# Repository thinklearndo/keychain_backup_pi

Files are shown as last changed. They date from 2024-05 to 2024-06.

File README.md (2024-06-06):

# keychain_backup_pi

## What is Keychain Backup Pi?

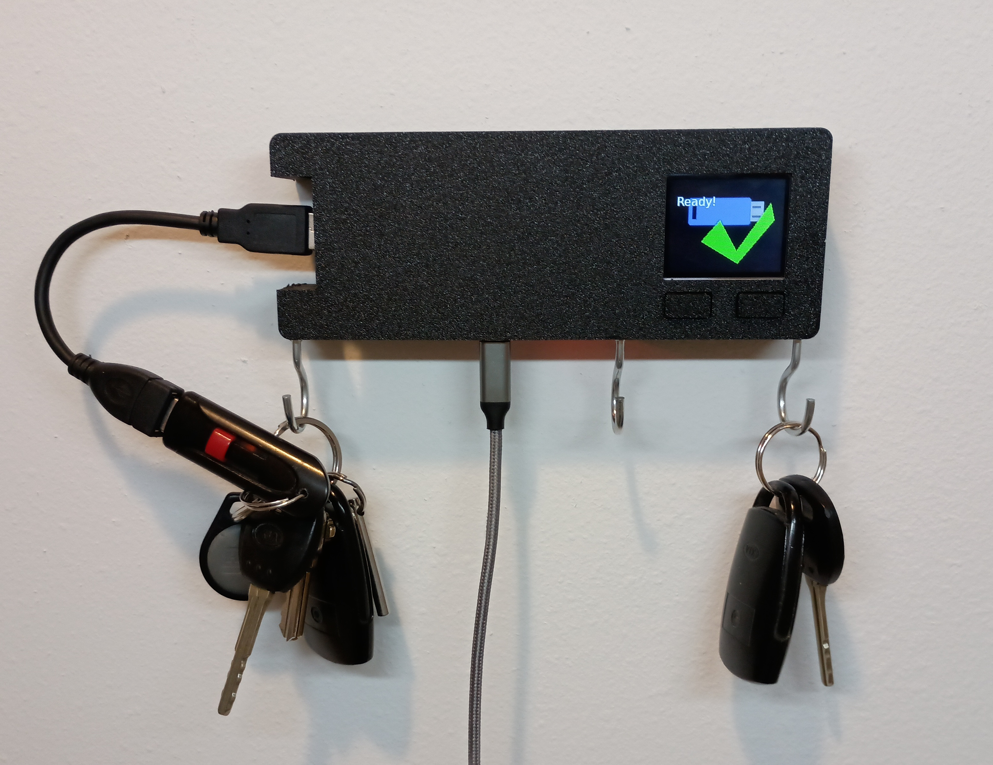
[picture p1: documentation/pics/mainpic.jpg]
 

This project is a backup system that allows keeping your important files with you all the time! Simply plug in your USB drive when you hang up your keys at night, backups run overnight over wifi, and in the morning take your freshly backed up files when you grab your keys. All powered by that amazing linux SBC, the raspberry pi.

## Improvements in this version:

* OLED LCD to give status and feedback.
* 2 buttons for interaction.
* Faster backups, 5-8 Mbytes/sec
* Easier access to the USB drive, using an extension cable.

## How it works:

Plug in you USB drive into the USB extension cable and hang your keys on a hook.

The LCD will display Ready! when the drive is ready for backups.

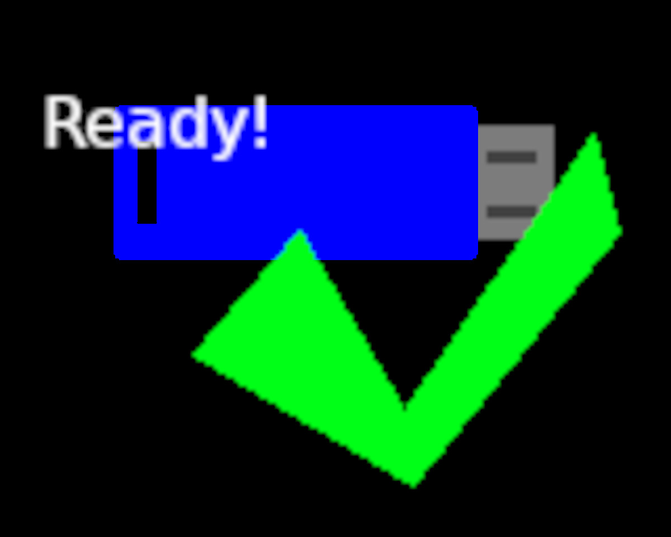
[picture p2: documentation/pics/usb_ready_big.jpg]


Let backups run over night.

In the morning when you are ready to take your keys, press one of the buttons on the front of the case. After a few moments, the LCD will show Safe to remove. Unplug the usb drive and take your keys.

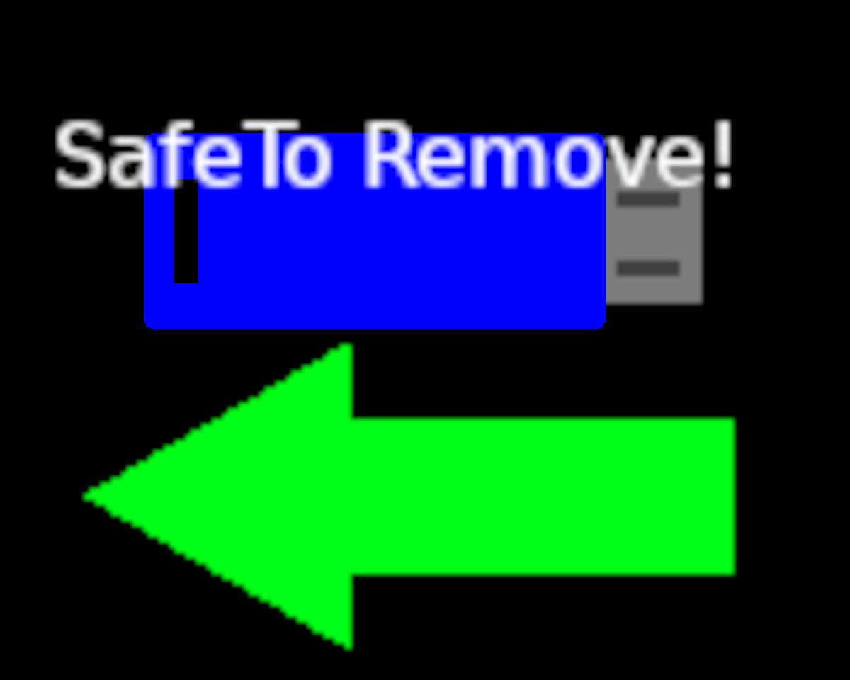
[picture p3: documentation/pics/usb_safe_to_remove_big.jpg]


## Setup

1. Follow the steps in [image flashing](documentation/imageFlashing.md) to get your sdcard setup with the keychain backup image.
2. If you aren't using the kit, [build from scratch](documentation/buildingFromScratch.md).
3. [Assemble the hardware](documentation/assembly.md).
4. [Mount it on the wall](documentation/mounting.md).

Finally, setup backups:

[Setup Duplicati for Windows, Mac and Linux](documentation/duplicatiSetup.md)

[Android file syncing instructions](documentation/androidSync.md)

[iPhone file syncing instructions](documentation/iphoneSync.md)

------------------
Please Note:

THE SOFTWARE IS PROVIDED “AS IS”, WITHOUT WARRANTY OF ANY KIND, EXPRESS OR IMPLIED, INCLUDING BUT NOT LIMITED TO THE WARRANTIES OF MERCHANTABILITY, FITNESS FOR A PARTICULAR PURPOSE AND NONINFRINGEMENT. IN NO EVENT SHALL THE AUTHORS OR COPYRIGHT HOLDERS BE LIABLE FOR ANY CLAIM, DAMAGES OR OTHER LIABILITY, WHETHER IN AN ACTION OF CONTRACT, TORT OR OTHERWISE, ARISING FROM, OUT OF OR IN CONNECTION WITH THE SOFTWARE OR THE USE OR OTHER DEALINGS IN THE SOFTWARE.

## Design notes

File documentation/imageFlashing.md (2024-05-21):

# Flashing the keychain backup image
Prerequisites:

Raspberry pi imager application installed, get it from here: https://www.raspberrypi.com/software/

SD card inserted into the computer

Image downloaded from our [release page.](https://github.com/thinklearndo/keychain_backup_pi/releases)

-----------

1. Run the pi imager application.
2. Click the Choose Device button.

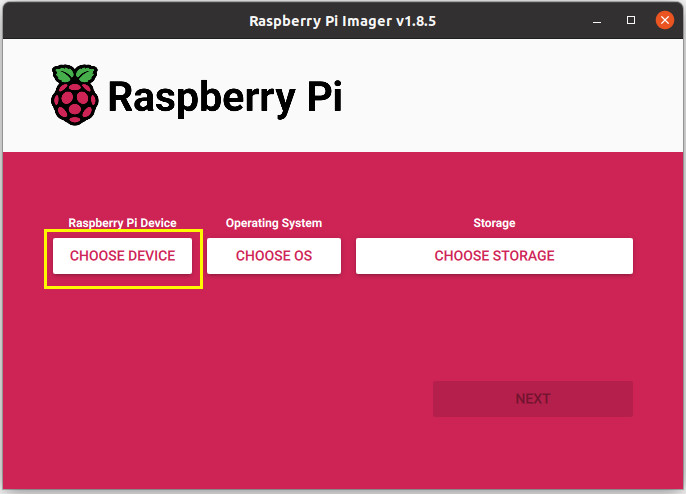
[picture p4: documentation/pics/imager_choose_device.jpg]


3. Select your raspberry pi. I have a raspberry pi 3a+ so I've selected Raspberry Pi 3.

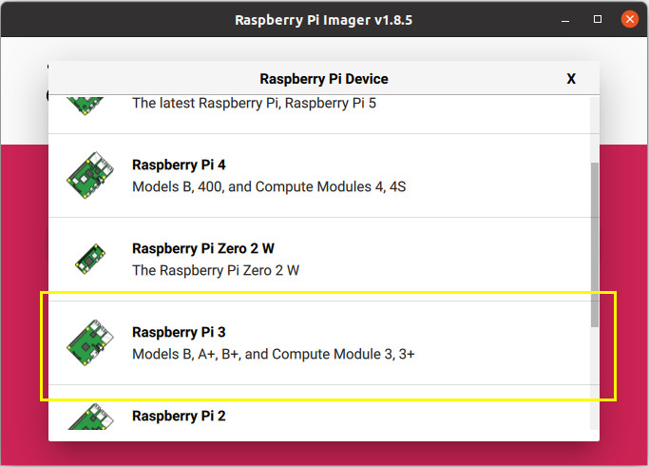
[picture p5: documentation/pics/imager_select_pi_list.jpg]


4. Back at the main screen click Choose OS.

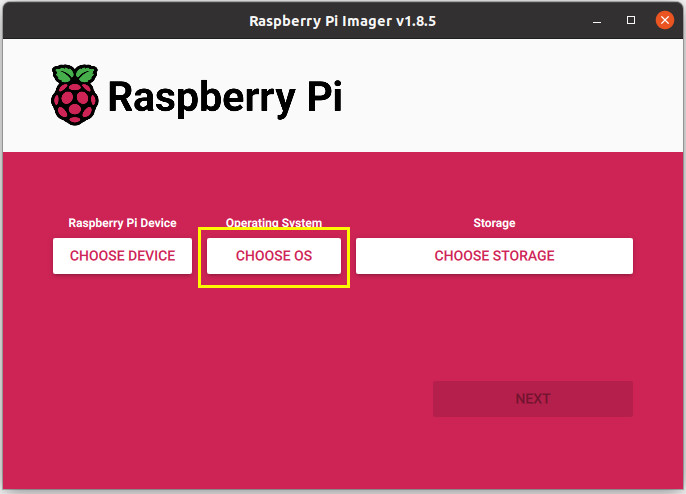
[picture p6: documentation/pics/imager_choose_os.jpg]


5. Scroll down to the bottom and select Use Custom.

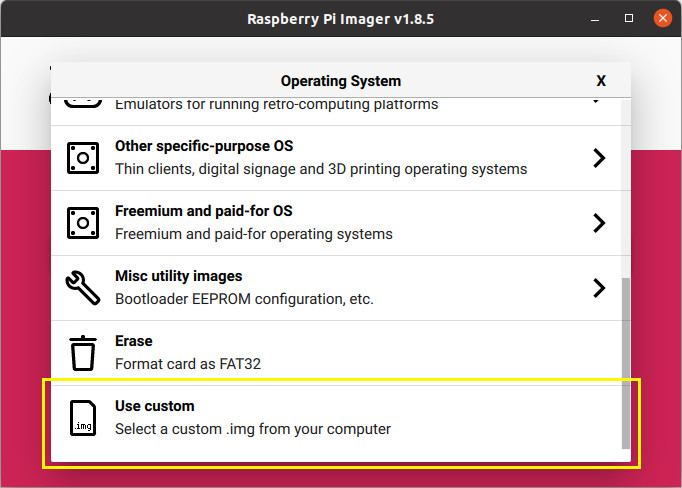
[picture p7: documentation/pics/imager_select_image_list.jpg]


6. Browse to the image file downloaded from our release page and click open.

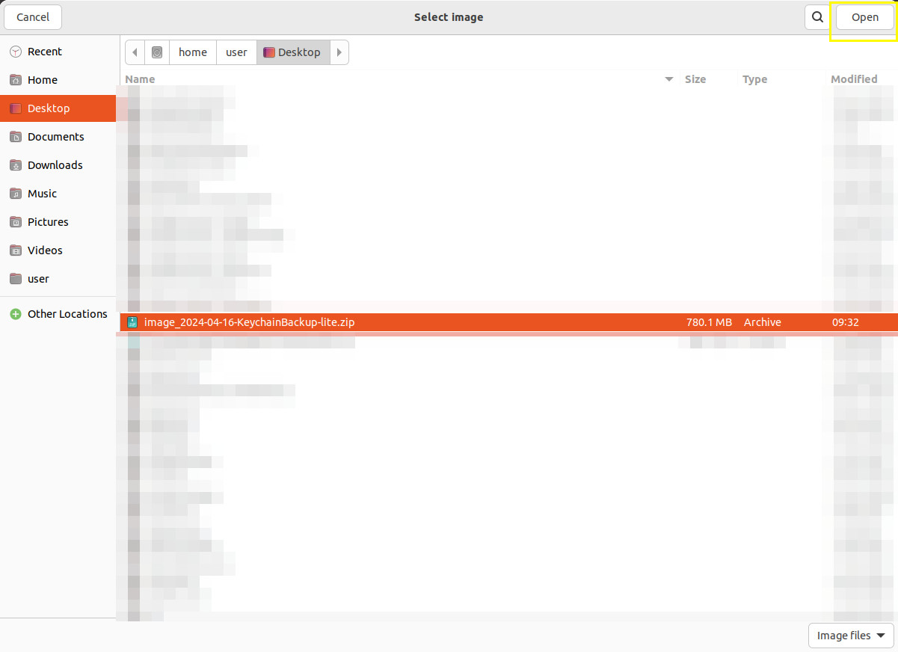
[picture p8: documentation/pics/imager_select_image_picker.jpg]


9. Click Choose storage button.

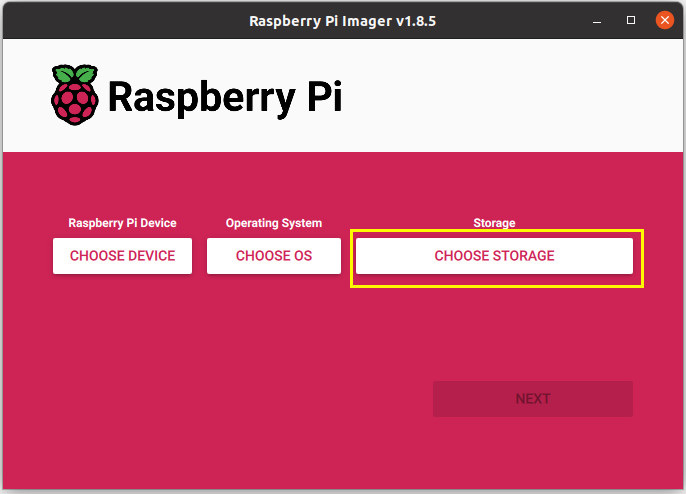
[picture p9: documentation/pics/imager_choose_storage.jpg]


10. Select the SD card you have inserted.

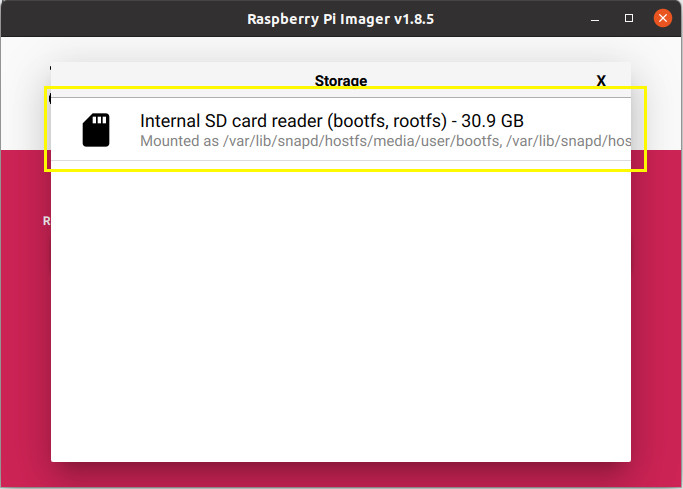
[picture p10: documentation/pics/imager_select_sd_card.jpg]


12. Click the Next button.

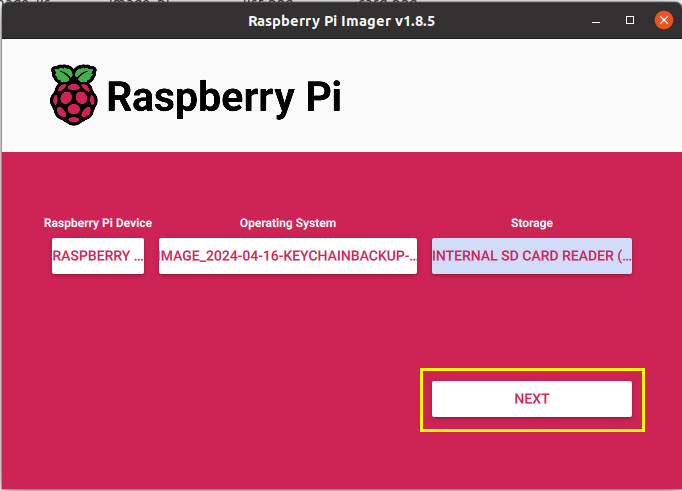
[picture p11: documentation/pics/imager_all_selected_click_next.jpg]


13. A Customise OS screen will pop up. Click edit settings.

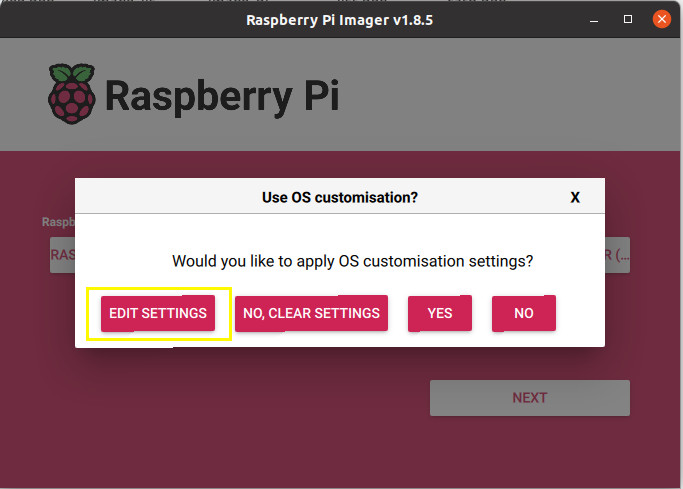
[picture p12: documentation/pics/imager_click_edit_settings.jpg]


14. On the General tab, Enter a hostname for the raspberry pi. This will make it easier to connect to later on. Also put in a username and password. You will need this later, so make a note of these values. Then set the wifi ssid and password.

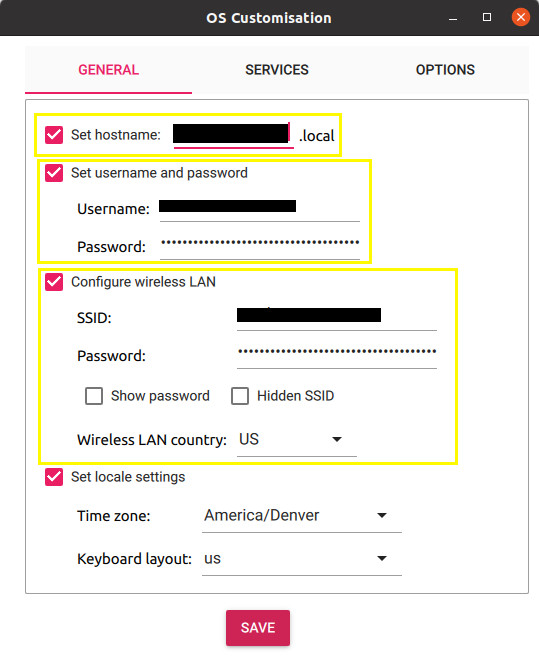
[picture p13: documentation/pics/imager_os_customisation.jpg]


15. Click on the Services tab. Make sure Enable SSH is checked and Use password authentication is selected. Then click the save button.

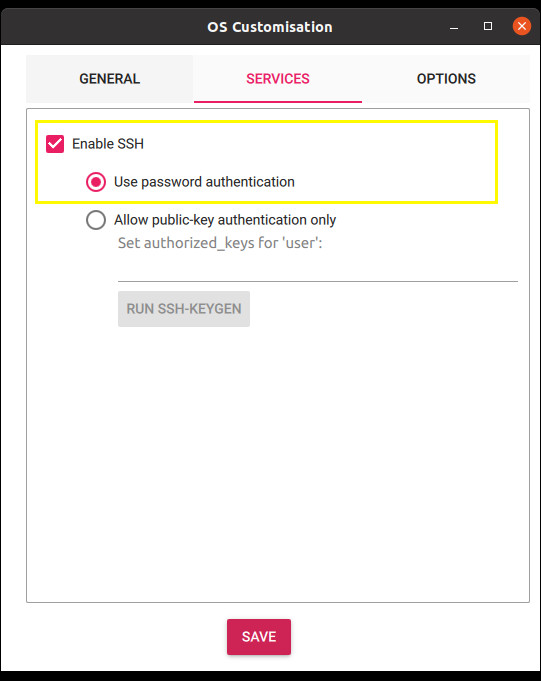
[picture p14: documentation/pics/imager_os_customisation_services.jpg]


16. Click on Yes, apply settings.

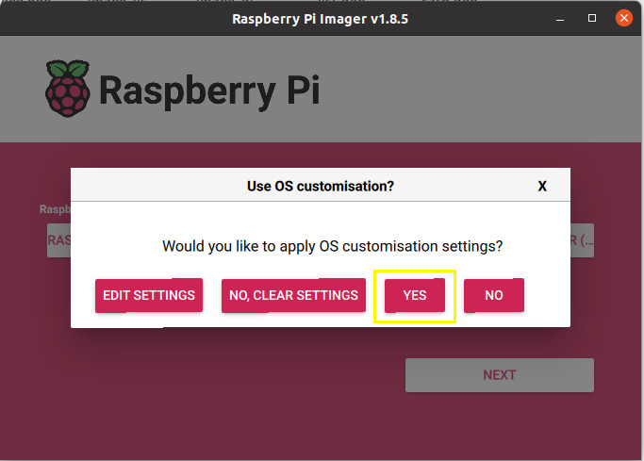
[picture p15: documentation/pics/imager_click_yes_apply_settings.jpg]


17. A warning will pop up about overwriting data, verify the right device is selected and click Yes.

18. Once the Write has finished, remove the SD card from the computer and insert it into the Raspberry PI. You are now ready to do the hardware setup, [Hardware Assembly](assembly.md).

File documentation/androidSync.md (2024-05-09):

## Using FolderSync app to sync files from Android to keychain backup

Before running this setup doc, make sure the USB drive is inserted into your Keychain backup device.

Install FolderSync app from the Play Store.

-----

1. Click create folderpair button.

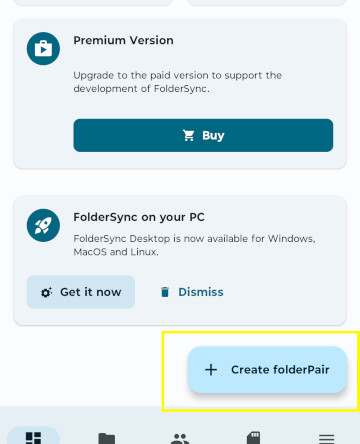
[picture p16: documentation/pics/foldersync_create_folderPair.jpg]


2. Give the folderpair a name and click next.

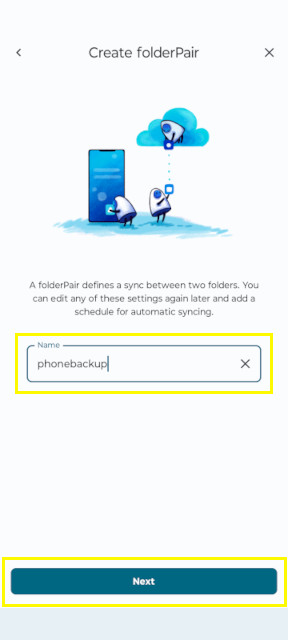
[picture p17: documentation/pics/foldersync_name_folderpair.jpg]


3. Leave Sync engine v2 selected and click next.

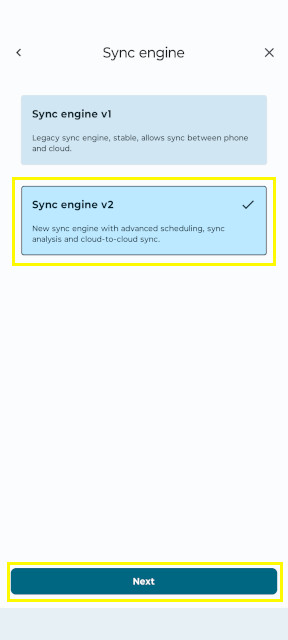
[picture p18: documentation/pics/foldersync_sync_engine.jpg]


4. Select To right folder and click next.

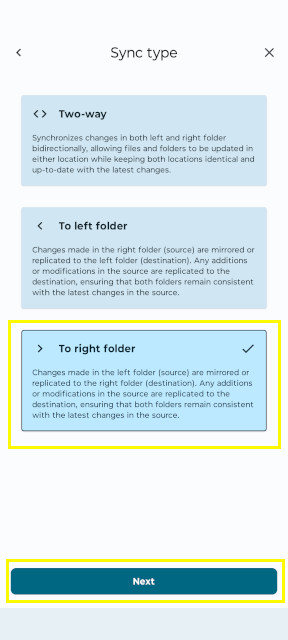
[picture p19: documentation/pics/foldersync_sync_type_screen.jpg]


5. On the Sync folders click on Select folder under Left folder.

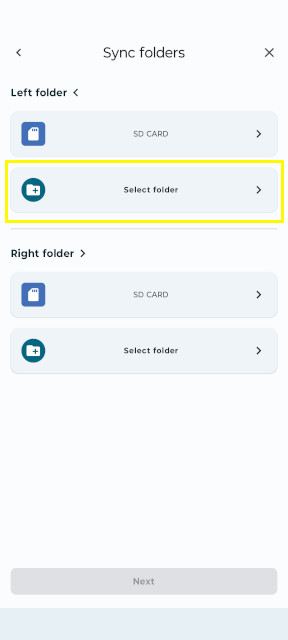
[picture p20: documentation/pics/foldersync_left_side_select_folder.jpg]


6. Select the folder to be backed up. For pictures and videos on Android, that would be the DCIM folder. Then click Select.

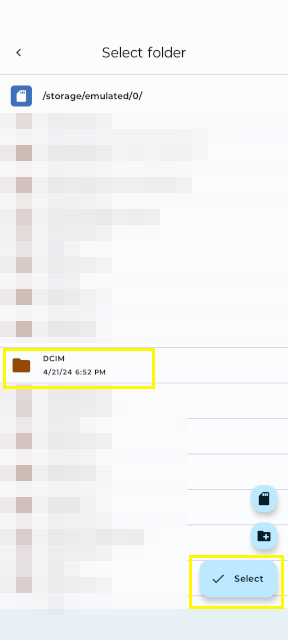
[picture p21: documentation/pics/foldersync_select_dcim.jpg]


7. Back at the Sync folders screen, under Right folder click on SD CARD.

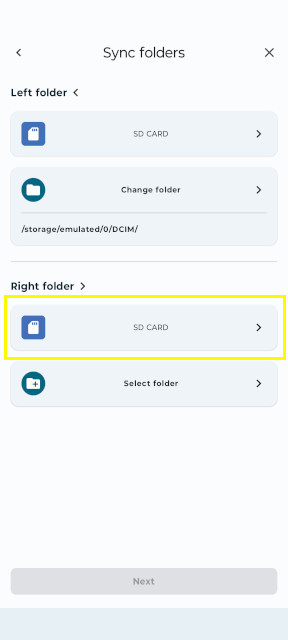
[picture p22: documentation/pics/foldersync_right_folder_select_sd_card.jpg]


8. Click Add account.

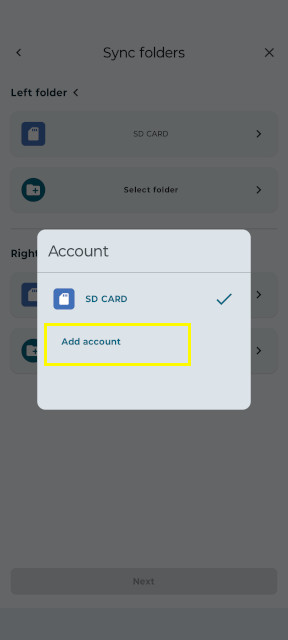
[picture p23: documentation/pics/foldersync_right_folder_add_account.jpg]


9. Scroll to the bottom and select SFTP under File protocols.

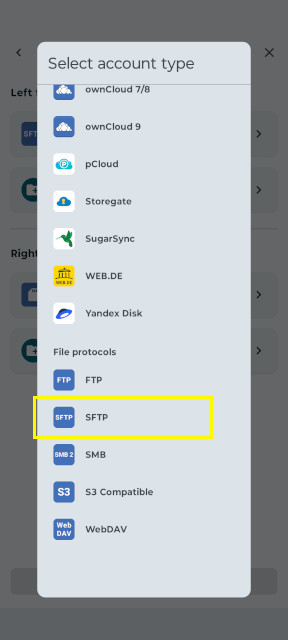
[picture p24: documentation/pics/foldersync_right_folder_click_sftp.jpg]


10. Click on the little pencil in the upper right corner and give the account a name.

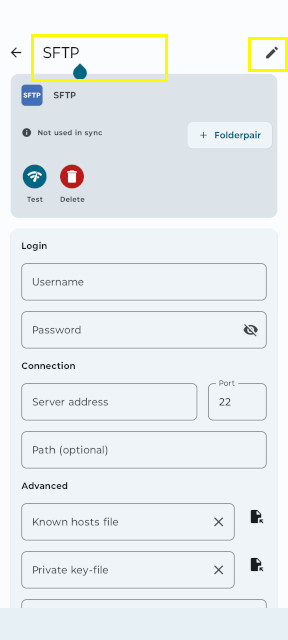
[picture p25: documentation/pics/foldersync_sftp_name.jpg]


11. Under login, enter the username and password you used to setup the raspberry pi.

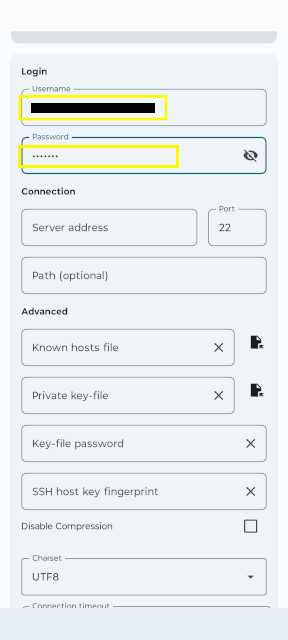
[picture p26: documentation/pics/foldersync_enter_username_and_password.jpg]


12. Under Connection, in the server address box, put in the IP address or host name of the keychain backup device and in the Port box put 2222.

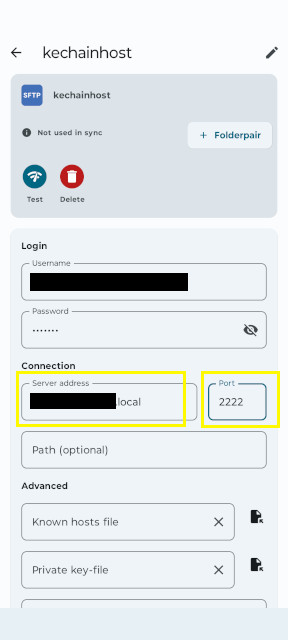
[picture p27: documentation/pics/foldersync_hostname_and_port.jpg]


13. Once all the info has been entered, click the back arrow in the upper left corner.



14. Back at the Sync folders screen, click on the SD CARD button under Right folder again. Select the newly created host.



15. In the Select folder window, click media, then click usbdrive.



16. Then click the Add folder button in the lower right corner.



17. In the create folder screen, enter a descriptive name for this backup storage location. This will allow mulitple android devices to backup to this USB drive.



18. Then click on the newly created folder.



19. Finally click on Select button.



20. Then click Next on the Sync folders screen.



21. Then click save.



22. To run the sync operation, click Sync.



23. To schedule syncs, click the Scheduling button.



24. Then click + schedule.

25. After setting up the schedule click save.

26. To verify that files are syncing, after the sync finishes, safely remove the usb drive and plug it into a computer. Open a file browser window and go to the usb device folder. Verify that the expected files are there.

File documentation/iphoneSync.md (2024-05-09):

### Setting up syncing for iPhone
----

Steps:

1. Install PhotoBackup from the app store (https://apps.apple.com/us/app/photobackup-backup-photos-and-videos-via-rsync/id945026388)

2. Allow PhotoBackup to connect to devices on your local network.



3. Click on Computer and enter in the hostname or IP address of your keychain backup device.



4. Enter your SSH credentials for your raspberry pi.



5. For remote folder enter /media/usbdrive



6. Allow PhotoBackup to access your photos.



7. Click Backup Camera Roll to backup your photos and videos to keychain backup.



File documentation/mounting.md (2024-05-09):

### Mounting the keyholder on the wall

-------------------

Tools needed:

* Pencil
* Drill
* 3/8" drill bit
* Screwdriver

Steps:

1. Place the wall bracket on the wall and mark screw holes with a pencil.



2. Remove the wall bracket and drill out the holes with a 3/8" drill bit.

3. Insert dry wall screw holders into the holes.



4. Align wall bracket with screw holes and screw 2 wall mounting screws, to secure it to the wall.



5. Align holes on top of the case with the holes on top of the wall bracket.



6. Screw in 2 - M4x5mm screws through the top of the case into the top of the wall bracket.



7. Connect strain relief USB extension cord to the side port.



8. Plug in the power to the raspberry pi by plugging in the USB cord to the micro USB port on the bottom of the pi's board. It will take up to a minute for the pi to turn on and the screen to show status messages.





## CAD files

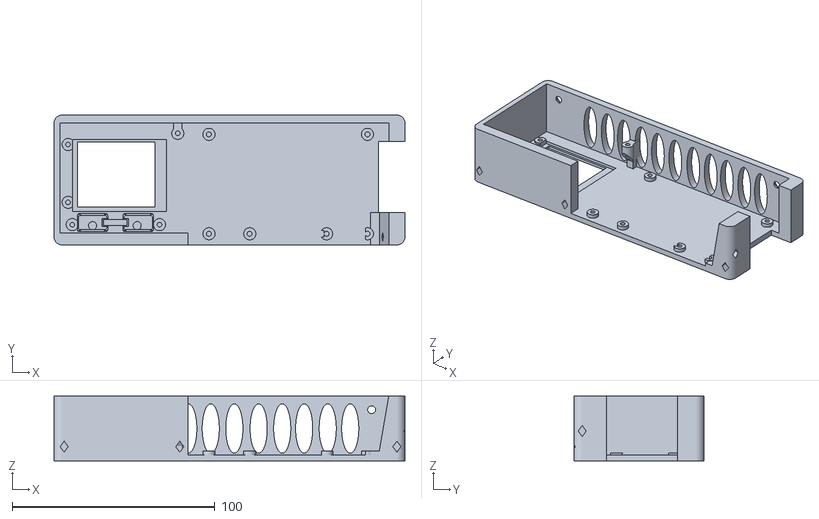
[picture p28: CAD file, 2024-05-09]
hardwarefiles/stl/keychain case.stl
173.0 x 64.0 x 32.0

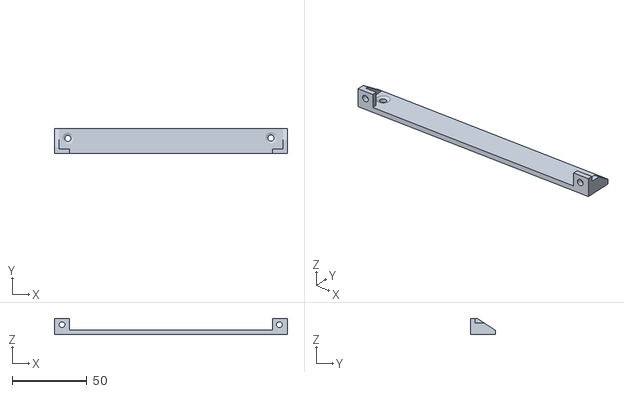
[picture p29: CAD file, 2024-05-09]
hardwarefiles/stl/wall mount.stl
156.0 x 17.0 x 11.0

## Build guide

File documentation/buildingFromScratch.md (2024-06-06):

# Building from Scratch

Get one of the connector PCB's made:

Raspberry pi 3a+ gerbers [hardwarefiles/pcb/pi3a](https://github.com/thinklearndo/keychain_backup_pi/tree/main/hardwarefiles/pcb/pi3a)

Raspberry pi 3b+ gerbers [hardwarefiles/pcb/pi3b](https://github.com/thinklearndo/keychain_backup_pi/tree/main/hardwarefiles/pcb/pi3b)

### Parts needed to finish the PCB:

2x 6x6x8mm SMD normally open SPST Momentary tactile switches (something like DTSM-65N-V-B, [mouser link](https://www.mouser.com/ProductDetail/Diptronics/DTSM-65N-V-B?qs=gTYE2QTfZfSXwXAGPNekUg%3D%3D))

1x 1x8 2.54mm pitch female header

1x 2x12 2.54mm pitch female header

### Other parts needed:

1x 1.8" oled lcd spi (here's one on [amazon](https://www.amazon.com/Display-Module-ST7735-128x160-STM32/dp/B07BFV69DZ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))

3x 1.25" Screw-in Cup Hooks

2x #6 screws and drywall mounts

2x m4x5mm screws

8x m2.6x4mm screws

Solder headers and buttons onto board:

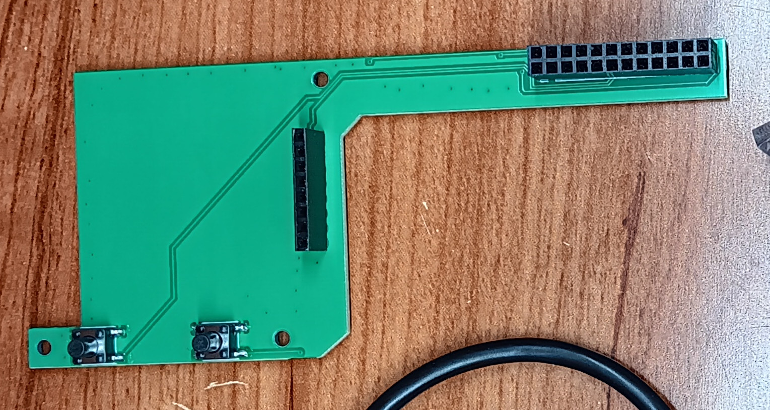
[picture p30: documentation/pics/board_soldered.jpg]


### Make the case:

Print out the [case](https://github.com/thinklearndo/keychain_backup_pi/blob/main/hardwarefiles/stl/keychain%20case.stl)

Print out the [wall bracket](https://github.com/thinklearndo/keychain_backup_pi/blob/main/hardwarefiles/stl/wall%20mount.stl)

Now you're ready to do the [hardware assembly](https://github.com/thinklearndo/keychain_backup_pi/blob/main/documentation/assembly.md)

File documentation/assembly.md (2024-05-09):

# Hardware Assembly

1. Plug in OLED LCD into 8 pin connection on the PCB.

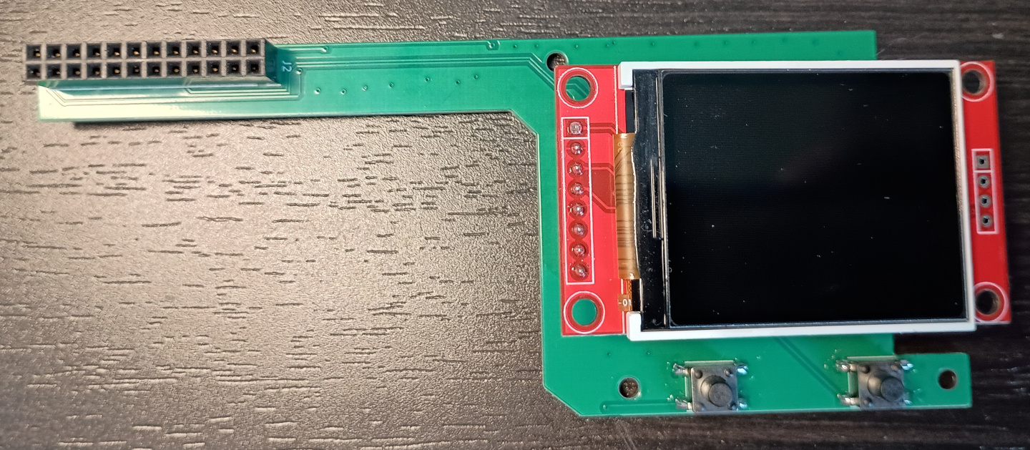
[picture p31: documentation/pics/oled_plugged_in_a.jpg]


2. Attach PCB to Raspberry pi expansion port.
   
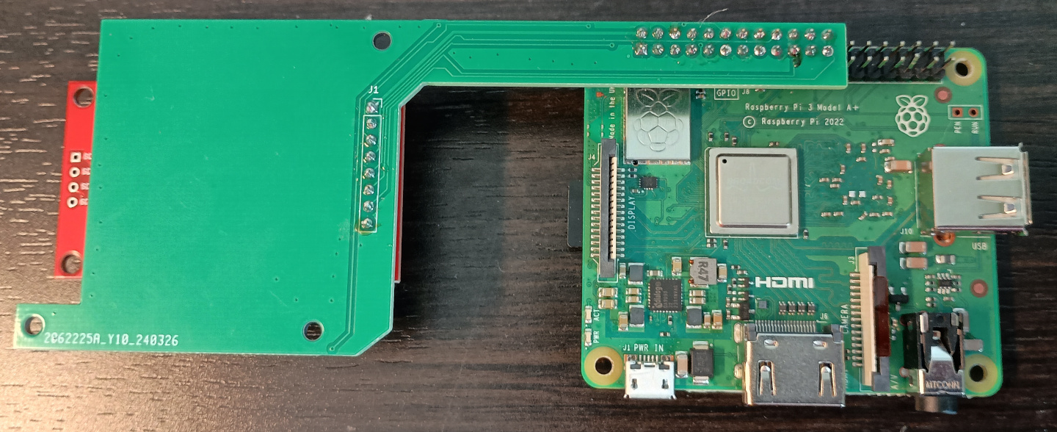
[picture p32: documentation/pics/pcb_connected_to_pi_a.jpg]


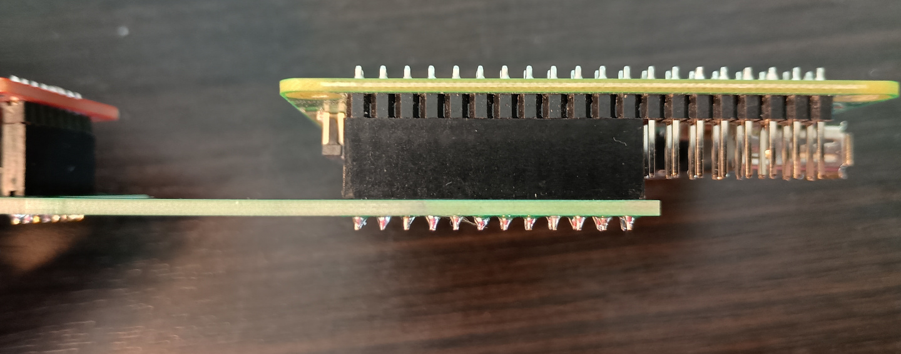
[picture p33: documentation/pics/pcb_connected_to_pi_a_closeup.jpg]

   
3. Screw in OLED LCD, PCB and Raspberry pi into the case. Be aware the buttons need to stick out of the case while screwing in the pcb.

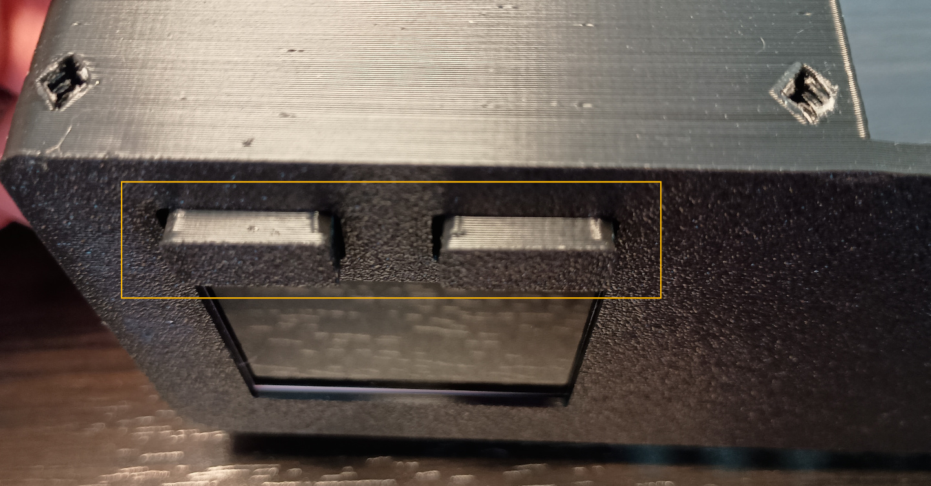
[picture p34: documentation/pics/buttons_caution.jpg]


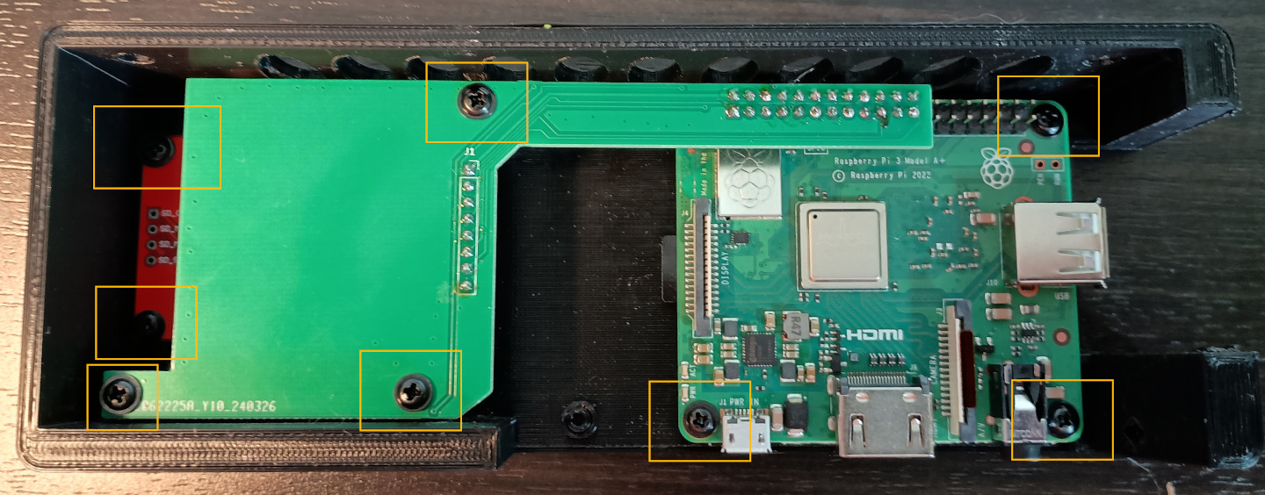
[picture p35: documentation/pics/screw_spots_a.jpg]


4. Screw in hooks to bottom of case.

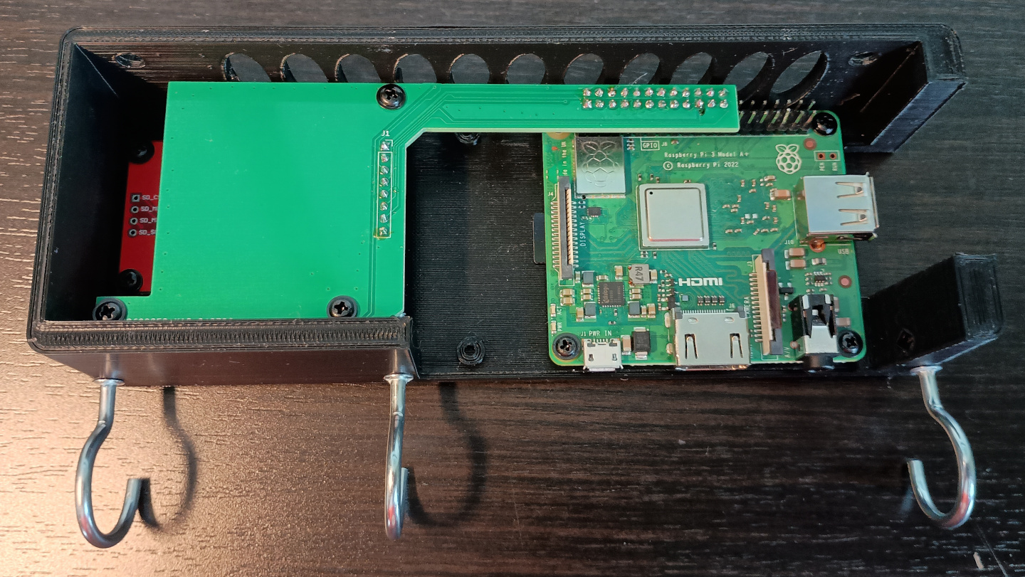
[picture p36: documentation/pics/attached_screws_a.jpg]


Now onto mounting the case on the wall: [Mounting the case](mounting.md)

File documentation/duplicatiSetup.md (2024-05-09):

## Using Duplicati to backup files to keychain backup

Before running this setup doc, make sure the USB drive is inserted into your Keychain backup device.

Download and install Duplicati for your platform: [https://duplicati.com/download](https://duplicati.com/download)

-----

1. Click add backup.

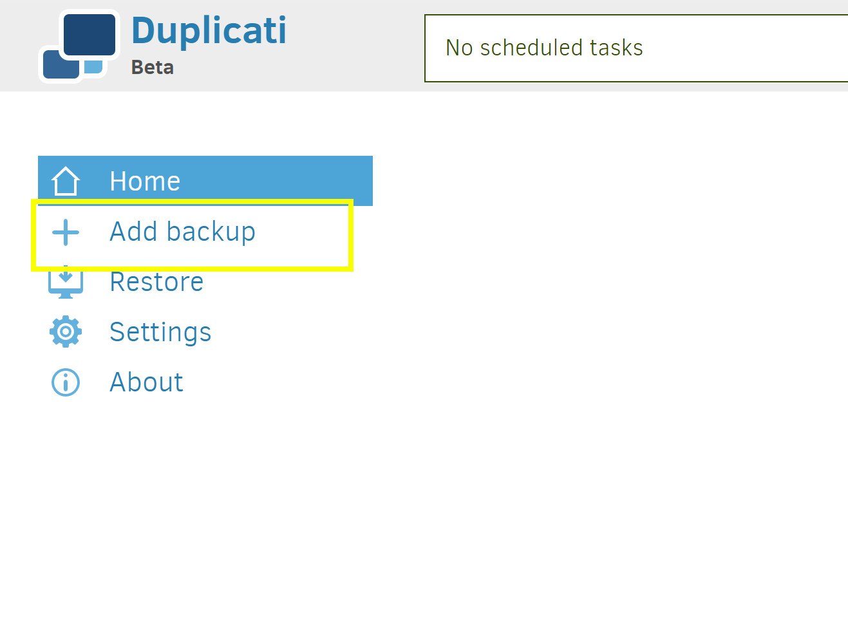
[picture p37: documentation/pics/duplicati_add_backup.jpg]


2. On Add a new backup screen, make sure Configure a new backup is selected and click Next.

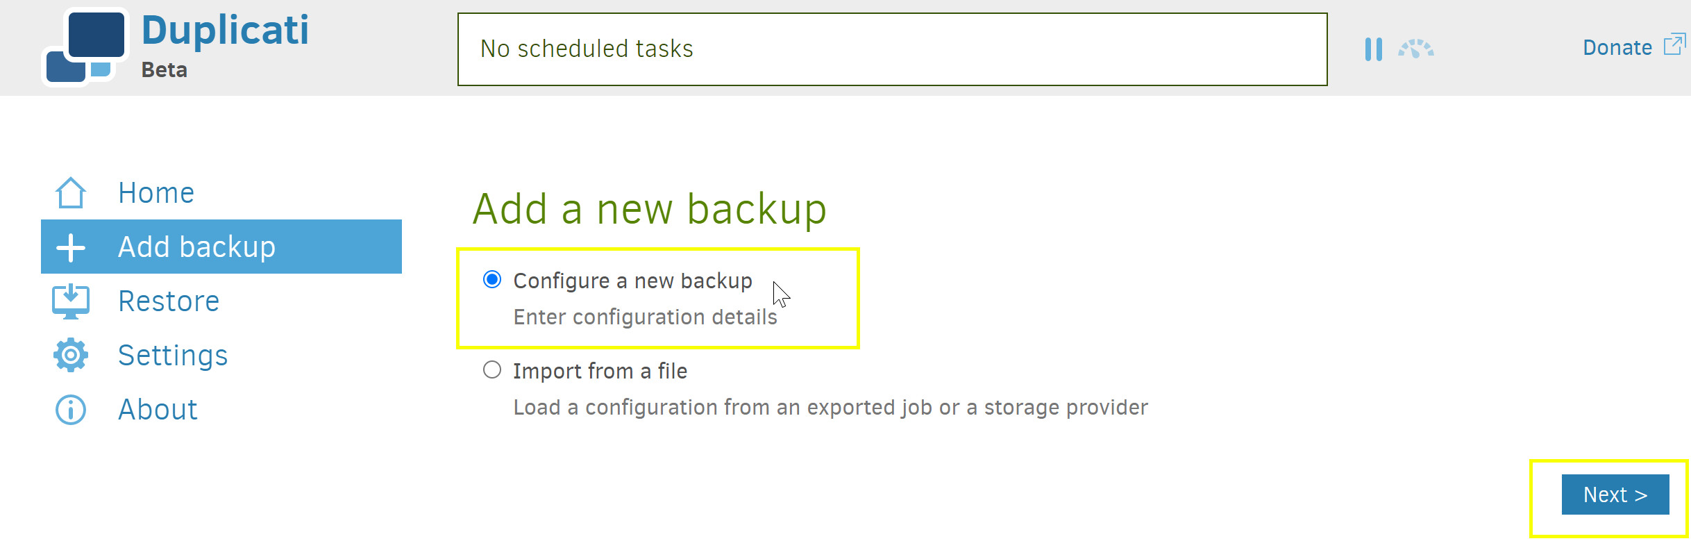
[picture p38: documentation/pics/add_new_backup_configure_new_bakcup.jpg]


3. On General backup settings, give it a name. Enter a good passphrase for the encryption, repeat it and click Next.

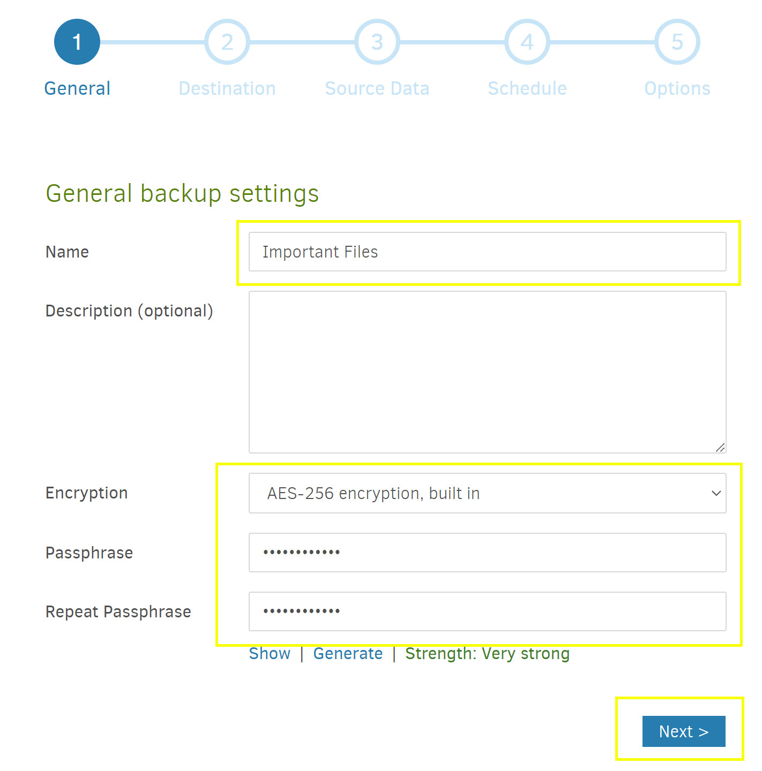
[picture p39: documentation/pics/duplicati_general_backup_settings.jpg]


4. On Backup destination, click the storage type dropdown and select SFTP(SSH).

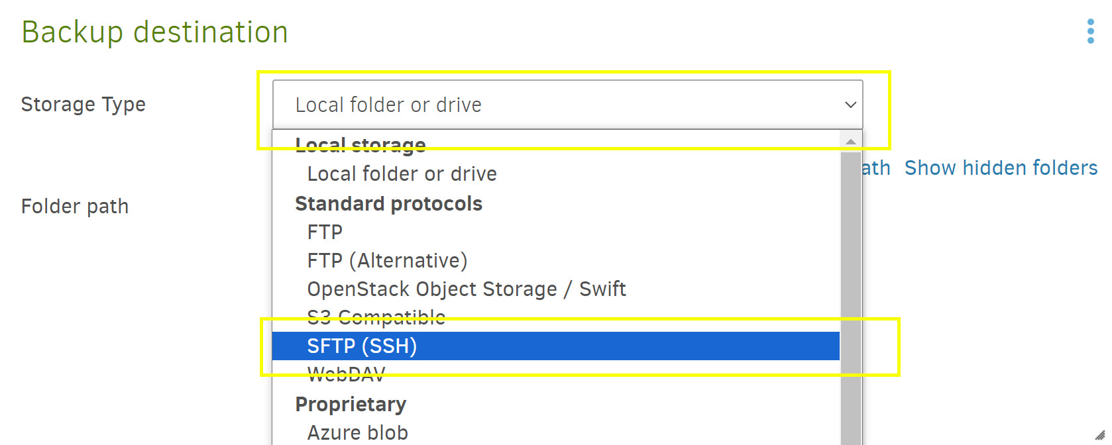
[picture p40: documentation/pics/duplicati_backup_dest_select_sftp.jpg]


5. Then put in the hostname or ip address of the keychain backup in the server box. Then put 2222 in the port box. For Path on server put /media/usbdrive. Then enter the username and password for the raspberry pi, that you picked when setting it up. Click Test connection.

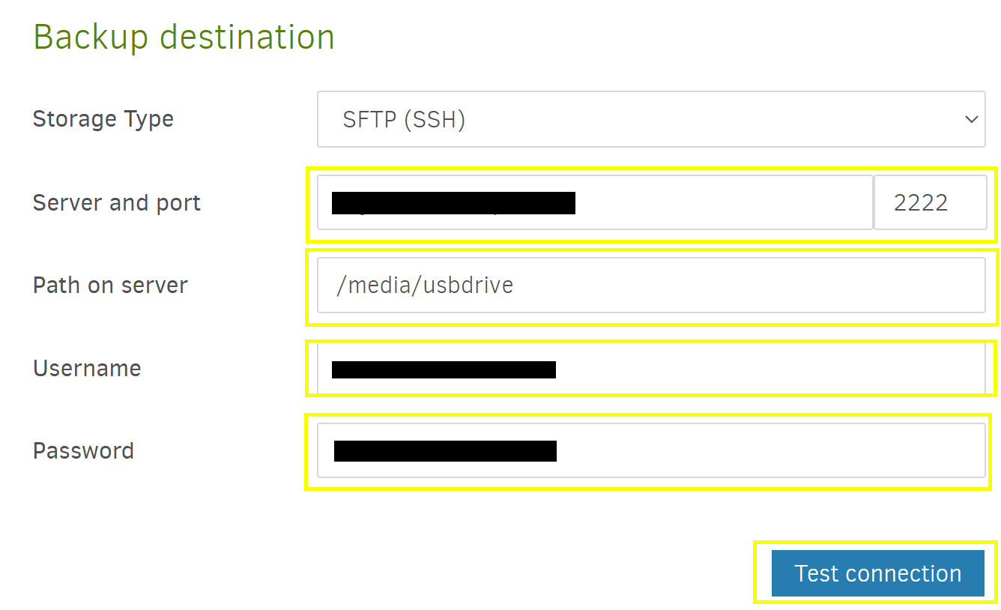
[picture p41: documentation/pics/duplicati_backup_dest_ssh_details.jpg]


6. It will ask to trust the host, click yes. It will pop up a dialog box say connection was successful, click ok. Then click Next.

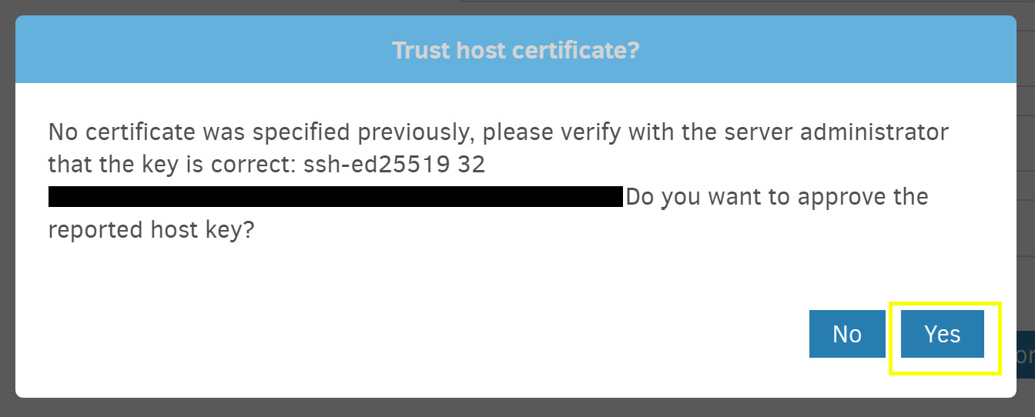
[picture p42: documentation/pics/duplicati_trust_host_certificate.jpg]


7. On the Source Data screen, select the folders/files you want backed up. Then click Next.

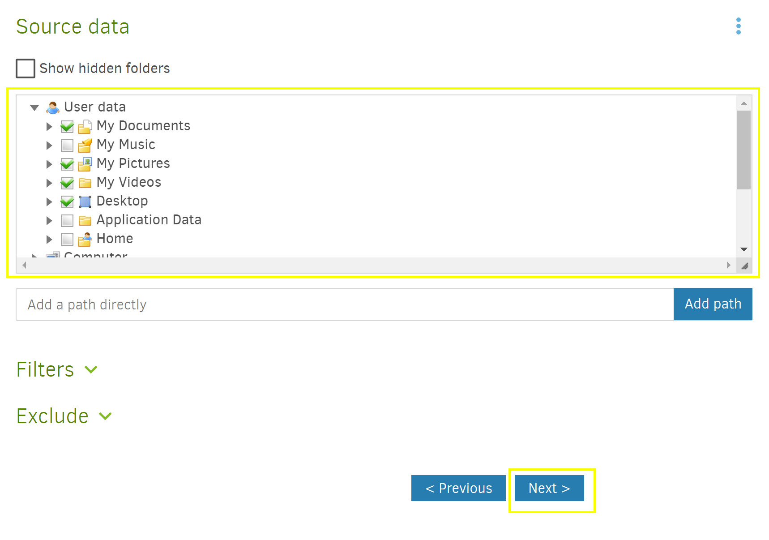
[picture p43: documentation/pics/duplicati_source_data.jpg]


8. On the Schedule page, setup when and how often the backup should run. Keep in mind when your keys will be hanging up and the usb drive will be plugged in.

9. On the general options page, make sure Backup retention is set to Keep all backups. Then click save.

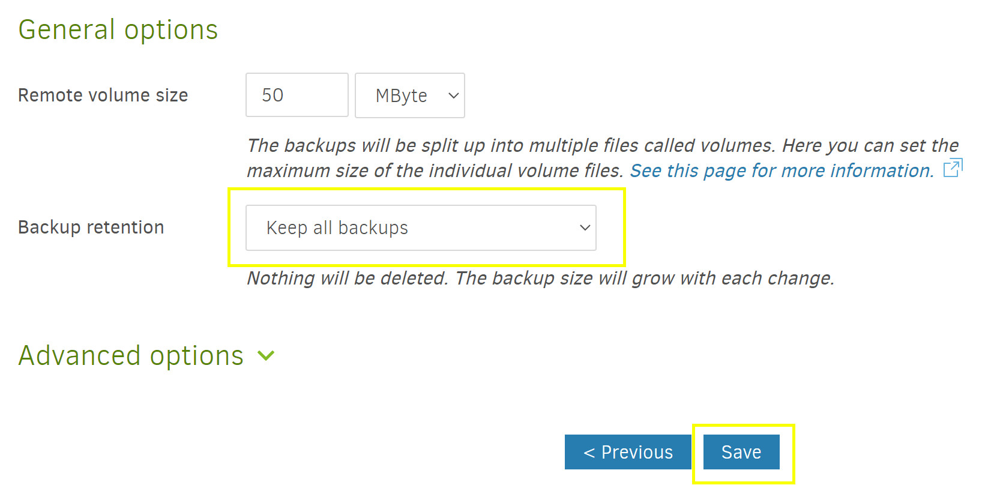
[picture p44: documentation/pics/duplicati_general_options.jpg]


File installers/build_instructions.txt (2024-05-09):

Building a debian installer for keychainbackup:

inside debian folder is keychainbackup-x.x folder, where x.x corresponds to the version that is being built.

copy all the folders and files from filesystem to the keychainbackup-x.x folder.

update the information in keychainbackup-x.x/DEBIAN/control for the build.

Build the package using the command: dpkg-deb --build keychainbackup-x.x/

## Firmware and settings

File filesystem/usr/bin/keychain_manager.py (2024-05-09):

#/bin/python3
import time
from enum import Enum
import subprocess
import digitalio
import board
from adafruit_rgb_display import st7735
from PIL import Image, ImageDraw, ImageFont
import datetime
from collections import deque

class DriveState(Enum):
	NO_DRIVE = 1
	DRIVE_MOUNTING = 2
	DRIVE_MOUNTED = 3
	REMOVE_REQUESTED = 4
	MOUNT_FAILED = 5
	
class PortState(Enum):
	CLOSED = 1
	OPEN = 2
	
class BackupState(Enum):
	NOT_RUNNING = 1
	RUNNING = 2
	
class ButtonState(Enum):
	NO_ACTION = 1
	DOWN = 2
	CLICKED = 3

class ScreenState(Enum):
	OFF = 1
	ON = 2
	
class WifiState(Enum):
	DISCONNECTED = 1
	WAITING = 2
	CONNECTED = 3

def is_drive_available():
	result = subprocess.run(['ls', '/dev/'], stdout=subprocess.PIPE).stdout.decode('utf-8')
	
	for line in result.split('\n'):
		if "sda" in line:
			return True
	return False
	
def get_drive_location():
	result = subprocess.run(['mount'], stdout=subprocess.PIPE).stdout.decode('utf-8')
				
	for line in result.split('\n'):
		if "sda1" in line:
			return line.split()[2].strip()
	
	return ""

def is_drive_mounted():
	result = subprocess.run(['mount'], stdout=subprocess.PIPE).stdout.decode('utf-8')
				
	for line in result.split('\n'):
		if "sda1" in line:
			actualMountLocation = line.split()[2]
			return True

	return False

def is_wifi_connected():
	result = subprocess.run(['iwgetid', '--raw'], stdout=subprocess.PIPE).stdout.decode('utf-8').rstrip()
	
	if len(result) == 0:
		# iwgetid --raw returns an empty string if not connected to a wifi network
		return False
	
	return True
	
def draw_image(display, image_file):
	image = Image.open(image_file)
	display.image(image)

def turn_on_screen(backlight_pin):
	backlight_pin.value = True
	return ScreenState.ON, time.time()

def turn_off_screen(backlight_pin):
	backlight_pin.value = False
	return ScreenState.OFF, -1

def is_usb_space_low(drive_location, low_disk_space_k):
	result = subprocess.run(['df', '-h', drive_location, '--output=avail', '-k'], stdout=subprocess.PIPE).stdout.decode('utf-8')
	
	free_space_int = int(result.split('\n')[1].rstrip())
	
	if (free_space_int <= low_disk_space_k):
		return True
	
	return False
	
def close_port():
	print("closing port")
	subprocess.run(['iptables', '-t', 'nat', '-F'])
	
	return PortState.CLOSED
	
def force_umount():
	subprocess.run(['systemctl', 'stop', 'sshd'])
	
	WaitForUnmountStartTimeSeconds = time.time()
			
	while is_drive_mounted() == True and time.time() - WaitForUnmountStartTimeSeconds <= 5:
	
		time.sleep(0.1)
		
		subprocess.run(['killall', 'sshd'])
	
		subprocess.run(['mount', '-f', '-o', 'remount,ro', '/dev/sda1'])
	
		subprocess.run(['umount', '/dev/sda1'])
		
	
	subprocess.run(['systemctl', 'start', 'sshd'])
	

def main():
	DefaultDriveMountLocation = "/media/usbdrive"
	ActualDriveMountLocation = ""
	ScreenOnTimeDelaySeconds = 15
	
	LowDiskSpaceWarningAmountK = 1000000 # 1 GB in KB
	LowDiskSpaceCheckDelaySeconds = 5
	LowDiskLastCheckTimeSeconds = 0

	CurrentDriveState = DriveState.NO_DRIVE
	CurrentPortState = PortState.CLOSED
	CurrentBackupState = BackupState.NOT_RUNNING
	CurrentWifiState = WifiState.WAITING
	CurrentLowDiskSpace = False
	
	Button1CurrentState = ButtonState.NO_ACTION
	Button2CurrentState = ButtonState.NO_ACTION
	
	CurrentScreenState = ScreenState.OFF
	ScreenTurnOnTimeSeconds = -1
	
	RemoveRequestStartTimeSeconds = -1
	RemoveRequestTimeLimitSeconds = 60
	ShouldCheckForRemoveRequest = False
	
	WaitForWifiStartTimeSeconds = time.time()
	WaitForWifiTimeLimitSeconds = 60
	
	DriveMountingStartTimeSeconds = -1
	DriveMountingTimeLimitSeconds = 12
	
	# this command runs top in the background in batch mode(-b) 2 samples(-n 2) with a 1 second delay between them (-d 1)
	TopStatsProcess = subprocess.Popen(['top', '-b', '-n', '2', '-d', '1'], stdout=subprocess.PIPE)
	sshdFoundQueue = deque()
	mmcWorkerFoundQueue = deque()
	
	#setup buttons
	button1 = digitalio.DigitalInOut(board.D18)
	button2 = digitalio.DigitalInOut(board.D27)

	button1.direction = digitalio.Direction.INPUT
	button1.pull = digitalio.Pull.UP

	button2.direction = digitalio.Direction.INPUT
	button2.pull = digitalio.Pull.UP
	#end button setup
	
	cs_pin = digitalio.DigitalInOut(board.CE0)
	dc_pin = digitalio.DigitalInOut(board.D25)
	reset_pin = digitalio.DigitalInOut(board.D24)
	backlight_pin = digitalio.DigitalInOut(board.D17)
	backlight_pin.direction = digitalio.Direction.OUTPUT
	BAUDRATE = 24000000
	
	spi = board.SPI()
	
	display = st7735.ST7735R(spi, rotation=90,
		cs=cs_pin,
		dc=dc_pin,
		rst=reset_pin,
		baudrate=BAUDRATE,
	)
	
	largeFont = font = ImageFont.truetype("/usr/share/fonts/truetype/dejavu/DejaVuSans.ttf", 24)
	
	image_folder = "/usr/share/keychain_manager/"
	usb_image = image_folder + "usb.jpg"
	usb_bad_image = image_folder + "usb_bad.jpg"
	usb_good_image = image_folder + "usb_good.jpg"
	usb_good_low_space_image = image_folder + "usb_good_no_space.jpg"
	usb_wait_image = image_folder + "usb_wait.jpg"
	blank_screen_image = image_folder + "blank.jpg"
	no_usb_idle_image = image_folder + "no_usb_idle.jpg"
	safe_to_remove_image = image_folder + "safe_to_remove.jpg"
	safe_to_remove_low_space_image = image_folder + "safe_to_remove_no_space.jpg"
	wifi_good_image = image_folder + "wifi_good.jpg"
	wifi_wait_image = image_folder + "wifi_wait.jpg"
	wifi_bad_image = image_folder + "wifi_bad.jpg"
	backup_running_image = image_folder + "backup_running.jpg"
	backup_running_low_space_image = image_folder + "backup_running_no_space.jpg"

	print("keychain manager started!")
	
	WaitForWifiStartTimeSeconds = time.time()
	
	while True:
		time.sleep(0.05) # sleep for 50 ms
		
		if button1.value == True and Button1CurrentState == ButtonState.DOWN:
			Button1CurrentState = ButtonState.CLICKED
		elif button1.value == False:
			Button1CurrentState = ButtonState.DOWN
			
		if button2.value == True and Button2CurrentState == ButtonState.DOWN:
			Button2CurrentState = ButtonState.CLICKED
		elif button2.value == False:
			Button2CurrentState = ButtonState.DOWN
		
		if ShouldCheckForRemoveRequest == True and Button1CurrentState == ButtonState.CLICKED:
		
			draw_image(display, usb_wait_image)
			CurrentScreenState, ScreenTurnOnTimeSeconds = turn_on_screen(backlight_pin)
		
			print("unmounting!")
			CurrentPortState = close_port()
			unmount_process = subprocess.run(['umount', '/dev/sda1'], stdout=subprocess.PIPE)
			
			WaitForUnmountStartTimeSeconds = time.time()
			
			while unmount_process.returncode != 0 and time.time() - WaitForUnmountStartTimeSeconds <= 5:
				time.sleep(0.05)
				unmount_process = subprocess.run(['umount', '/dev/sda1'], stdout=subprocess.PIPE)
				print("waiting for unmount success!")
			
			if time.time() - WaitForUnmountStartTimeSeconds > 5:
				print("force unmounting!")
				force_umount()
			
			draw_image(display, safe_to_remove_image)
			CurrentScreenState, ScreenTurnOnTimeSeconds = turn_on_screen(backlight_pin)
			CurrentDriveState = DriveState.REMOVE_REQUESTED
			RemoveRequestStartTimeSeconds = time.time()
			ShouldCheckForRemoveRequest = False
		elif ShouldCheckForRemoveRequest == True and CurrentScreenState == ScreenState.OFF:
			ShouldCheckForRemoveRequest = False

		if CurrentDriveState == DriveState.DRIVE_MOUNTED and time.time() - LowDiskLastCheckTimeSeconds > LowDiskSpaceCheckDelaySeconds:
			CurrentLowDiskSpace = is_usb_space_low(ActualDriveMountLocation, LowDiskSpaceWarningAmountK)
			LowDiskLastCheckTimeSeconds = time.time()
			
		if TopStatsProcess.poll() != None:
			# process finished, get some info for checking if a backup is running
			
			if CurrentDriveState == DriveState.DRIVE_MOUNTED:
			
				lineCount = 0
				foundSshd = False
				foundMmcWorker = False
				
				for line in TopStatsProcess.communicate()[0].decode('utf-8').split('\n'):
					# sshd and mmc worker should be in the top 15 lines of tops output
					# don't even need to check cpu usage, if they are there, they are doing work
					lineCount = lineCount + 1
					
					if "sshd" in line:
						#print(line)
						foundSshd = True
					
					if "mmc" in line:
						#print(line)
						foundMmcWorker = True
					
					if lineCount > 15:
						break
						
				
				sshdFoundQueue.append(foundSshd)
				mmcWorkerFoundQueue.append(foundMmcWorker)
				
				if len(sshdFoundQueue) > 5:
					sshdFoundQueue.popleft()
					mmcWorkerFoundQueue.popleft()
				
				sshdCount = 0
				mmcCount = 0
				for item in sshdFoundQueue:
					if item == True:
						sshdCount = sshdCount + 1
				
				for item in mmcWorkerFoundQueue:
					if item == True:
						mmcCount = mmcCount + 1
						
				mountBusy = False
				
				mountUsageResult = subprocess.run(['fuser', '-m', '/dev/sda1'], stdout=subprocess.PIPE).stdout.decode('utf-8')
				
				for line in mountUsageResult.split('\n'):
					if "sda1" in line:
						mountBusy = True
				
				# at least 2 Trues and we'll say a backup is running
				if sshdCount >= 2 or mmcCount >= 2 or mountBusy == True:
					CurrentBackupState = BackupState.RUNNING
				else:
					CurrentBackupState = BackupState.NOT_RUNNING
			
			#start the stats process again
			TopStatsProcess = subprocess.Popen(['top', '-b', '-n', '2', '-d', '1'], stdout=subprocess.PIPE)
				
		
		wifiCheckResult = is_wifi_connected()
		
		if CurrentWifiState != WifiState.CONNECTED and wifiCheckResult == True:
			CurrentWifiState = WifiState.CONNECTED
			WaitForWifiStartTimeSeconds = -1
			draw_image(display, blank_screen_image)
			CurrentScreenState, ScreenTurnOnTimeSeconds = turn_on_screen(backlight_pin)
			draw_image(display, wifi_good_image)
		
		if CurrentWifiState == WifiState.WAITING and time.time() - WaitForWifiStartTimeSeconds > WaitForWifiTimeLimitSeconds:
			CurrentWifiState = WifiState.DISCONNECTED
			WaitForWifiStartTimeSeconds = -1
			draw_image(display, blank_screen_image)
			CurrentScreenState, ScreenTurnOnTimeSeconds = turn_on_screen(backlight_pin)
			draw_image(display, wifi_bad_image)
		
		if CurrentWifiState == WifiState.CONNECTED and wifiCheckResult == False:
			CurrentWifiState = WifiState.DISCONNECTED
			WaitForWifiStartTimeSeconds = -1
			draw_image(display, blank_screen_image)
			CurrentScreenState, ScreenTurnOnTimeSeconds = turn_on_screen(backlight_pin)
			draw_image(display, wifi_bad_image)
		
		if CurrentDriveState == DriveState.NO_DRIVE:
			if is_drive_available() == True and is_drive_mounted() == False:
					
				print("found drive, but not mounted... Mounting")
				draw_image(display, blank_screen_image)
				
				CurrentScreenState, ScreenTurnOnTimeSeconds = turn_on_screen(backlight_pin)
			
				draw_image(display, usb_wait_image)
				
				subprocess.run(['mkdir', '-p', DefaultDriveMountLocation], stdout=subprocess.PIPE)
				
				#check if its ext* filesystem
				isVfat = True
				filesysteminfo = subprocess.run(['file', '-sL', '/dev/sda1'], stdout=subprocess.PIPE).stdout.decode('utf-8')
				for line in filesysteminfo.split('\n'):
					if "ext" in line:
						isVfat = False
			
				if isVfat == True:
					subprocess.Popen(['mount', '-o', 'uid=1000,gid=1000', '/dev/sda1', DefaultDriveMountLocation])
				else:
					subprocess.Popen(['mount', '/dev/sda1', DefaultDriveMountLocation])
			
				CurrentDriveState = DriveState.DRIVE_MOUNTING
				DriveMountingStartTimeSeconds = time.time()
				
			elif is_drive_available() == True and is_drive_mounted() == True:
				ActualDriveMountLocation = get_drive_location()
				print("Drive mounted at", ActualDriveMountLocation)
				CurrentDriveState = DriveState.DRIVE_MOUNTED
		
		elif CurrentDriveState == DriveState.DRIVE_MOUNTING:
			print("checking if its mounted yet...")
			if is_drive_mounted() == True:
				print("Yay its mounted!")
				ActualDriveMountLocation = get_drive_location()
				CurrentDriveState = DriveState.DRIVE_MOUNTED
			
			if time.time() - DriveMountingStartTimeSeconds > DriveMountingTimeLimitSeconds:
				CurrentDriveState = DriveState.MOUNT_FAILED
				draw_image(display, blank_screen_image)
				draw_image(display, usb_bad_image)
				CurrentScreenState, ScreenTurnOnTimeSeconds = turn_on_screen(backlight_pin)
				DriveMountingStartTimeSeconds = -1
		
		elif CurrentDriveState == DriveState.REMOVE_REQUESTED:
			if is_drive_available() == False and is_drive_mounted() == False:
				CurrentDriveState = DriveState.NO_DRIVE
				draw_image(display, blank_screen_image)
				draw_image(display, no_usb_idle_image)
				CurrentScreenState, ScreenTurnOnTimeSeconds = turn_on_screen(backlight_pin)
			elif time.time() - RemoveRequestStartTimeSeconds > RemoveRequestTimeLimitSeconds:
				CurrentDriveState = DriveState.NO_DRIVE
				RemoveRequestStartTimeSeconds = -1
	
		elif CurrentDriveState == DriveState.MOUNT_FAILED:
			if is_drive_available() == False:
				CurrentDriveState = DriveState.NO_DRIVE
		
		elif CurrentDriveState == DriveState.DRIVE_MOUNTED:
			#check if drive is unexpectedly removed
			if is_drive_available() == False:
				if is_drive_mounted() == True:
					force_umount()
			
				print("drive unexpectedly removed")
				CurrentDriveState = DriveState.NO_DRIVE
		
		if CurrentDriveState == DriveState.DRIVE_MOUNTED and CurrentPortState == PortState.CLOSED:
			with open('/proc/sys/net/ipv4/ip_forward', "w") as ip_forward_file:
				subprocess.run(['echo', '1'], stdout=ip_forward_file)

			subprocess.run(['iptables', '-t', 'nat', '-A', 'PREROUTING', '-p', 'tcp', '--dport', '2222', '-j', 'REDIRECT', '--to-port', '22'])
			CurrentPortState = PortState.OPEN
			
			CurrentLowDiskSpace = is_usb_space_low(ActualDriveMountLocation, LowDiskSpaceWarningAmountK)
			
			draw_image(display, blank_screen_image)
			
			if CurrentLowDiskSpace == True:
				print("mounted low disk space")
				draw_image(display, usb_good_low_space_image)
					
			else:
				print("mounted plenty of disk space")
				draw_image(display, usb_good_image)

			CurrentScreenState, ScreenTurnOnTimeSeconds = turn_on_screen(backlight_pin)

		elif CurrentDriveState != DriveState.DRIVE_MOUNTED and CurrentPortState == PortState.OPEN:
			CurrentPortState = close_port()

		if CurrentScreenState == ScreenState.OFF and (Button1CurrentState == ButtonState.CLICKED or Button2CurrentState == ButtonState.CLICKED):
			draw_image(display, blank_screen_image)

			if CurrentWifiState == WifiState.WAITING:
				print("showing wifi waiting")
				draw_image(display, wifi_wait_image)
			elif CurrentWifiState == WifiState.DISCONNECTED:
				print("showing wifi bad")
				draw_image(display, wifi_bad_image)
			elif CurrentDriveState == DriveState.MOUNT_FAILED:
				print("showing bad drive")
				draw_image(display, usb_bad_image)
			elif CurrentDriveState == DriveState.NO_DRIVE:
				print("showing idle")
				draw_image(display, no_usb_idle_image)
			elif CurrentDriveState == DriveState.DRIVE_MOUNTING:
				print("showing mounting")
				draw_image(display, usb_wait_image)
			elif CurrentBackupState == BackupState.RUNNING:
				if CurrentLowDiskSpace == True:
					print("backup running low disk space")
					draw_image(display, backup_running_low_space_image)
					
				else:
					print("backup running")
					draw_image(display, backup_running_image)
				
				ShouldCheckForRemoveRequest = True
				
			elif CurrentDriveState == DriveState.DRIVE_MOUNTED and CurrentBackupState == BackupState.NOT_RUNNING:
				print("unmounting!")
				
				CurrentPortState = close_port()
				
				subprocess.run(['umount', '/dev/sda1'], stdout=subprocess.PIPE)
				
				if is_drive_mounted() == True:
					force_umount()
				
				if CurrentLowDiskSpace == True:
					print("showing safe to remove low space")
					draw_image(display, safe_to_remove_low_space_image)
					
				else:
					print("showing safe to remove")
					draw_image(display, safe_to_remove_image)

				CurrentDriveState = DriveState.REMOVE_REQUESTED
				RemoveRequestStartTimeSeconds = time.time()
				print("drivestate = ", CurrentDriveState)
			elif CurrentDriveState == DriveState.REMOVE_REQUESTED:
				if CurrentLowDiskSpace == True:
					print("showing safe to remove low space")
					draw_image(display, safe_to_remove_low_space_image)
					
				else:
					print("showing safe to remove")
					draw_image(display, safe_to_remove_image)

			CurrentScreenState, ScreenTurnOnTimeSeconds = turn_on_screen(backlight_pin)

		if Button1CurrentState == ButtonState.CLICKED:
			print("button1 clicked!")
			Button1CurrentState = ButtonState.NO_ACTION
			
		if Button2CurrentState == ButtonState.CLICKED:
			print("button2 clicked!")
			Button2CurrentState = ButtonState.NO_ACTION

		if CurrentScreenState == ScreenState.ON:
			if time.time() - ScreenTurnOnTimeSeconds > ScreenOnTimeDelaySeconds:
				CurrentScreenState, ScreenTurnOnTimeSeconds = turn_off_screen(backlight_pin)
				draw_image(display, blank_screen_image)
if __name__ == "__main__":
    main()

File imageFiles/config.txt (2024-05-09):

# For more options and information see
# http://rptl.io/configtxt
# Some settings may impact device functionality. See link above for details

# Uncomment some or all of these to enable the optional hardware interfaces
#dtparam=i2c_arm=on
#dtparam=i2s=on
dtparam=spi=on

# Enable audio (loads snd_bcm2835)
#dtparam=audio=on

# Additional overlays and parameters are documented
# /boot/firmware/overlays/README

# Automatically load overlays for detected cameras
#camera_auto_detect=1

# Automatically load overlays for detected DSI displays
#display_auto_detect=1

# Automatically load initramfs files, if found
auto_initramfs=1

# Enable DRM VC4 V3D driver
#dtoverlay=vc4-kms-v3d
#max_framebuffers=2

# Don't have the firmware create an initial video= setting in cmdline.txt.
# Use the kernel's default instead.
disable_fw_kms_setup=1

# Run in 64-bit mode
arm_64bit=1

# Disable compensation for displays with overscan
disable_overscan=1

# Run as fast as firmware / board allows
arm_boost=1

[cm4]
# Enable host mode on the 2711 built-in XHCI USB controller.
# This line should be removed if the legacy DWC2 controller is required
# (e.g. for USB device mode) or if USB support is not required.
otg_mode=1

[all]

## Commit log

2024-05-09 working version
    [config.txt, keychain case.stl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]
2024-06-06 add soldered board pic
2024-06-06 adding image of soldered board
